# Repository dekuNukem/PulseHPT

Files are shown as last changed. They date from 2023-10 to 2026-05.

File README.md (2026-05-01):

# PulseHPT 3-in-1 Shutter Speed Tester

[Purchase](https://www.tindie.com/products/33002/) | [Discord](https://discord.gg/yyRq8QtX4r) | [Instructions](#user-manual)

---

PulseHPT is a compact shutter speed tester for vintage cameras.

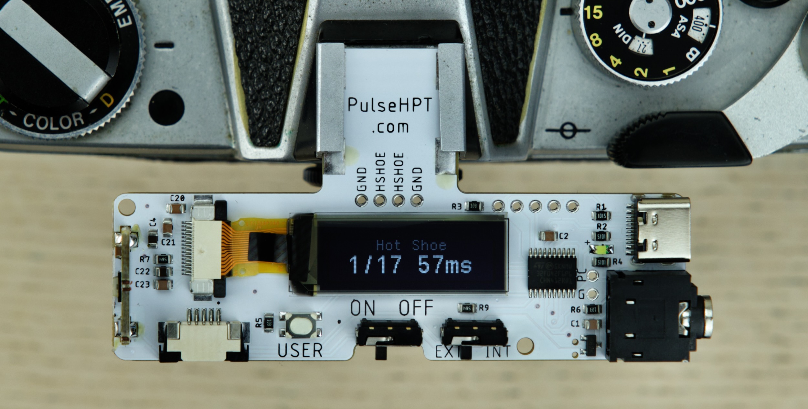
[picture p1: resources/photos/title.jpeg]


Quick and easy measurement from **multiple sources**:

* **Hot Shoe**
* **PC Socket**
* **Light Sensor**
	* Built-in & External
	* Leaf Shutter: All Speeds
	* Focal Plane Shutter: Within Flash Sync

Ideal for **in-the-field testing** of unknown cameras

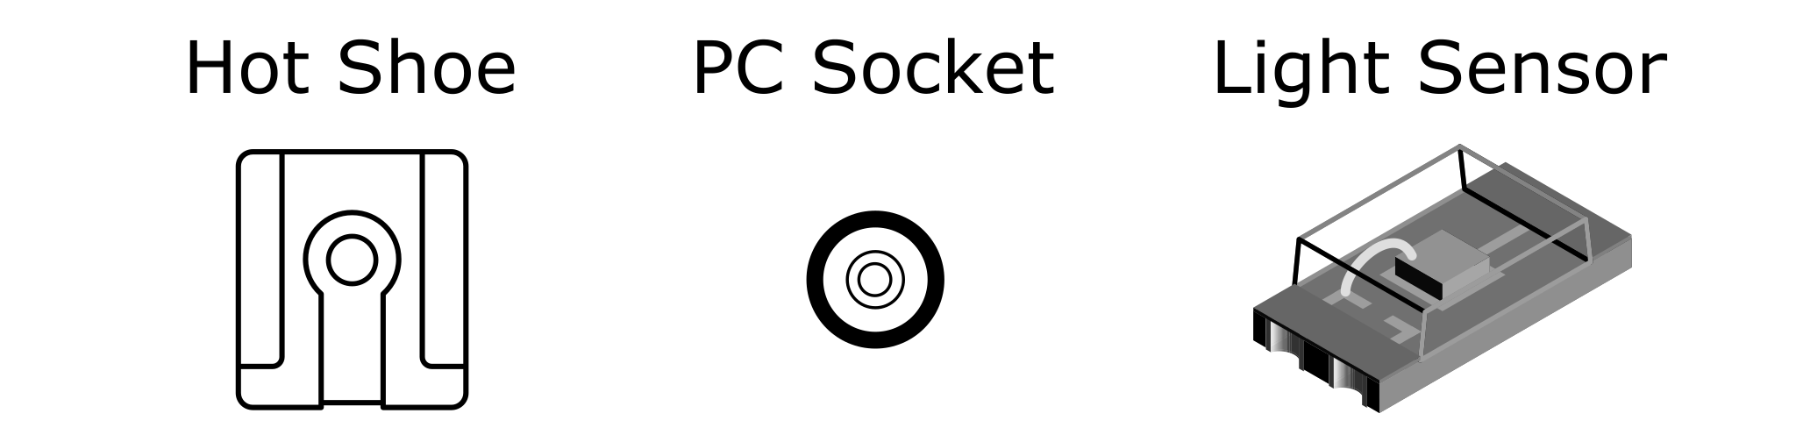
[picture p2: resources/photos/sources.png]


## Highlights

* Compact & Portable

* Multiple Sources

* Microsecond Accuracy

* 20-hour battery / 4000 measurements

## Buy One / Discussions

* United Kingdom: [https://www.ebay.co.uk/itm/365904291256](https://www.ebay.co.uk/itm/365904291256)

* Rest of the world: [https://www.tindie.com/products/33002/](https://www.tindie.com/products/33002/)

[Discord chatroom](https://discord.gg/yyRq8QtX4r) for questions and discussions. Or email `dekuNukem`@`gmail`.`com` .
 
# User Manual

- [Battery](#battery)

- [Hot Shoe](#measurement-hot-shoe)

- [PC Socket](#measurement-pc-socket)

- [Built-in Light Sensor](#measurement-light-sensor)

- [External Light Sensor](#external-light-sensor)

## Battery

* **CR2032**

* Positive (+) side up

* ⚠️ Slide UNDER the catch!

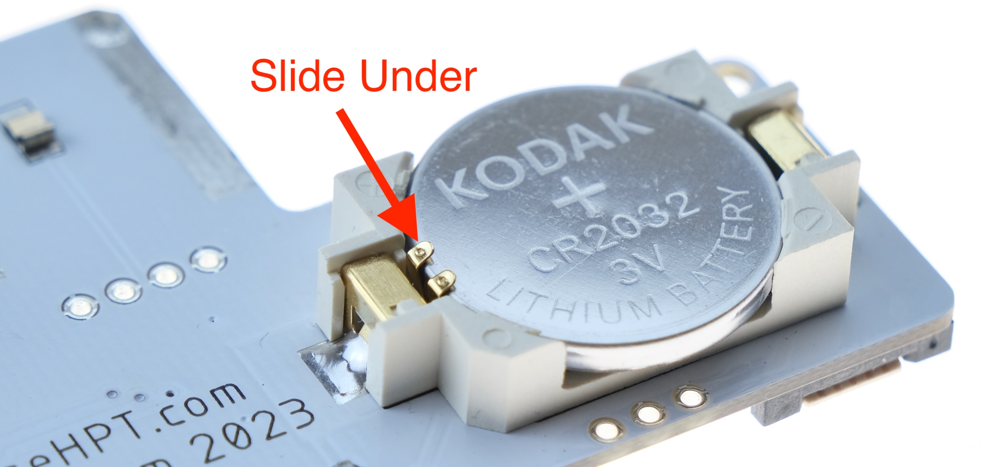
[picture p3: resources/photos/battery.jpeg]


## Measurement: Hot Shoe

* Insert into hot shoe
* Slide switch to ON
* Select a speed
	* Leaf Shutter: All Speeds
	* Focal Plane Shutter: **Within Flash Sync Speed**
* Wind and release the shutter

💭 If nothing happens, press down to ensure good contact.

⚠️ **Beware of caveats!** Read below.



#### How it works

When taking a photo, the flash sync signal activates, and remains active **until shutter is closed**.

Thus the approximate shutter speed can be measured.

#### Caveats

* Flash sync fires **only when shutter is fully open**.

* Thus at higher speeds, the measured speed can be faster than real speed.

* Works best with earlier mostly-mechanical cameras.

* For most accurate result, use the light sensor method.

## Measurement: PC Socket

* Use a common **PC socket to 3.5mm Jack** Cable

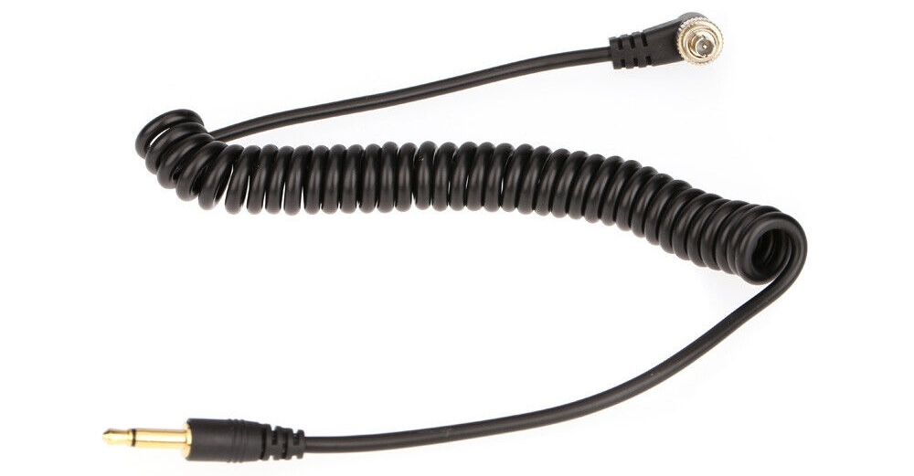
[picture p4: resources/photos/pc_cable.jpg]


* Plug into PC socket, and the other end in the tester.

* ⚠️ ⚠️ Make sure to use `X Sync` socket / option!

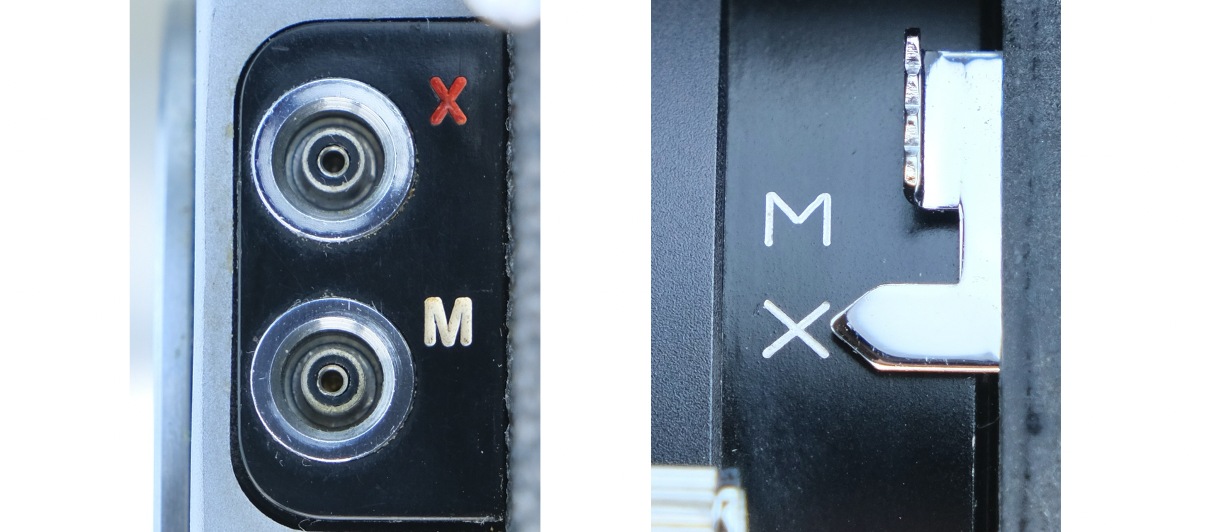
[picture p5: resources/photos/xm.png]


* Slide switch to ON
* Select a speed
	* Leaf Shutter: All Speeds
	* Focal Plane Shutter: **Within Flash Sync Speed**
* Wind and release the shutter

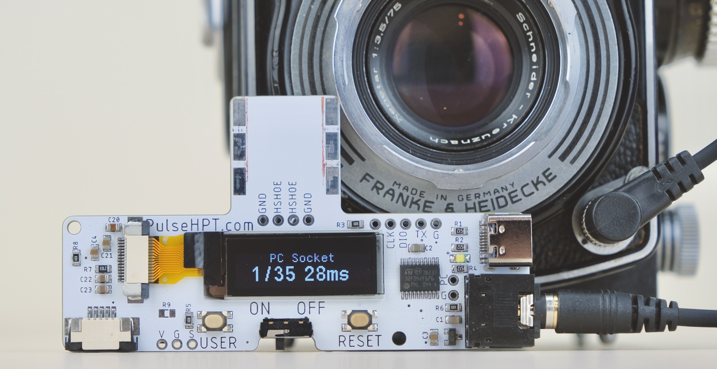
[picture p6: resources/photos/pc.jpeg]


💭 If nothing happens, apply **GENTLE** pressure on the PC socket to ensure good contact.

⚠️ Same caveats as hot shoe!

## Measurement: Light Sensor

* Most accurate
* Two Sources
	* Built-in Sensor: Easiest to Use
	* External Sensor: More Consistent Setup

## Built-in Light Sensor

The built-in sensor sticks out on the left-hand side.

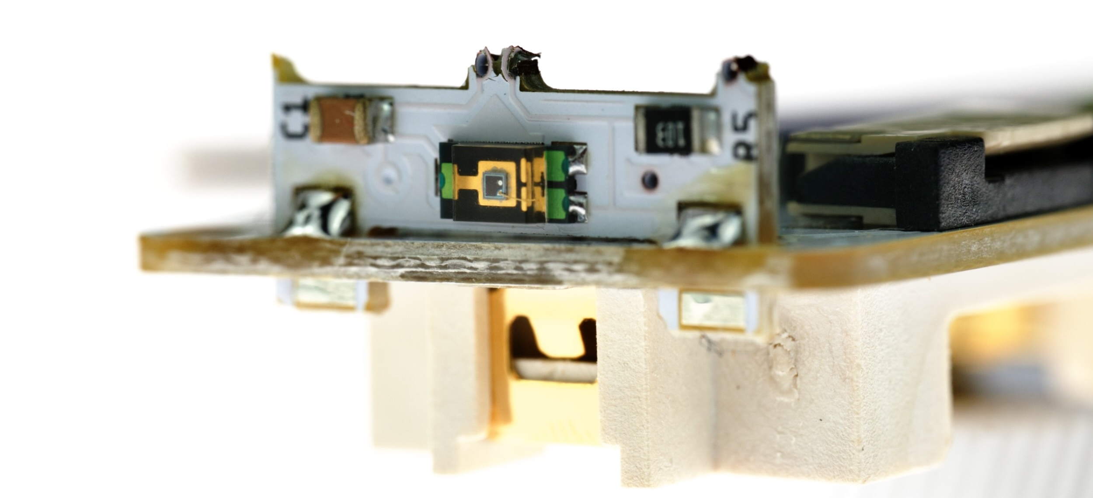
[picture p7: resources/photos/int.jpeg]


Slide the light sensor source switch to `INTERAL` position.

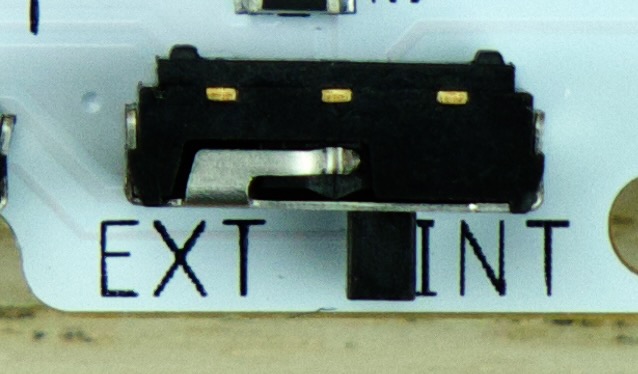
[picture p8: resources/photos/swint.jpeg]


Shine a bright light into the sensor.

It should trigger and give a measurement.

Now you know how bright the light needs to be.

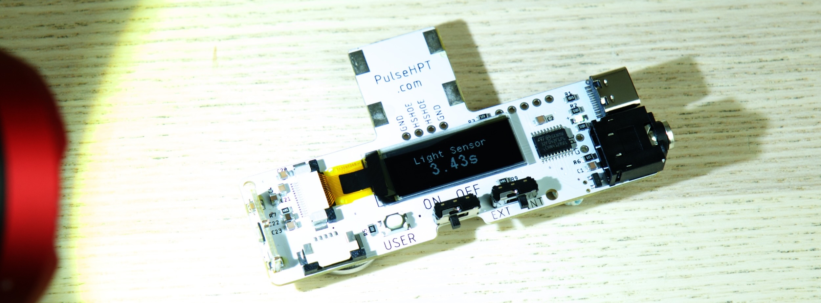
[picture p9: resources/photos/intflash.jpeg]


To test:

* Remove lens if possible
	* Largest aperture otherwise
* Shine light from front
* Place tester **near the center** of film gate
* Fire shutter
	* Leaf Shutter: All Speeds
	* Focal Plane Shutter: **Within Flash Sync Speed**

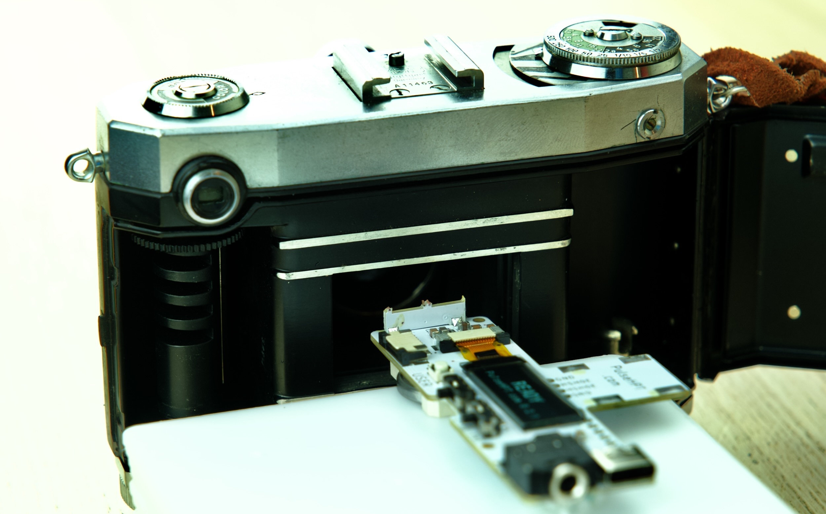
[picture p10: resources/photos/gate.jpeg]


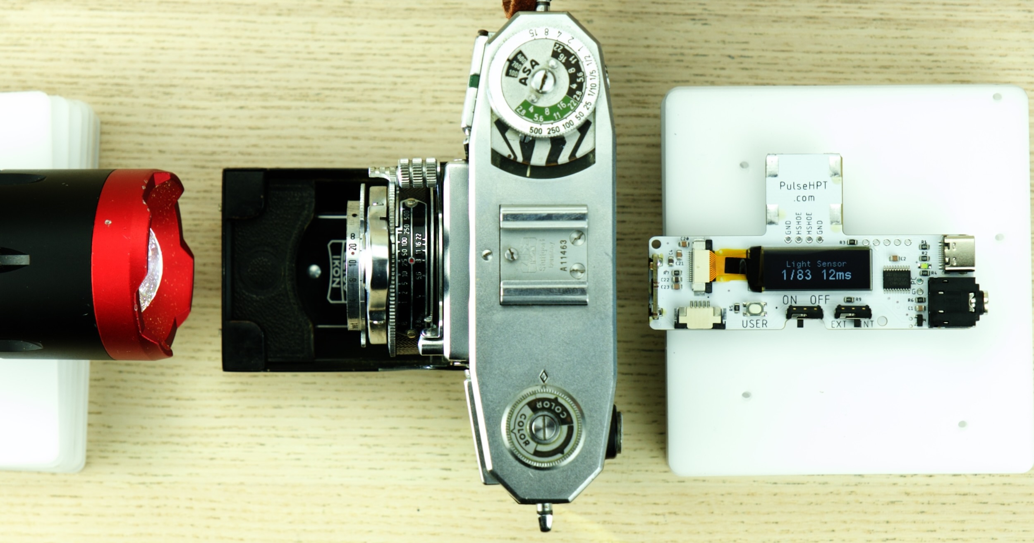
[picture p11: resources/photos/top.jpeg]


## External Light Sensor

Requires more setup, but can be more consistent. Also suitable for hard-to-reach places.

* Locate the connector on **bottom-left corner**.

* **SLOWLY and GENTLY** push the black tab outwards to unlock.

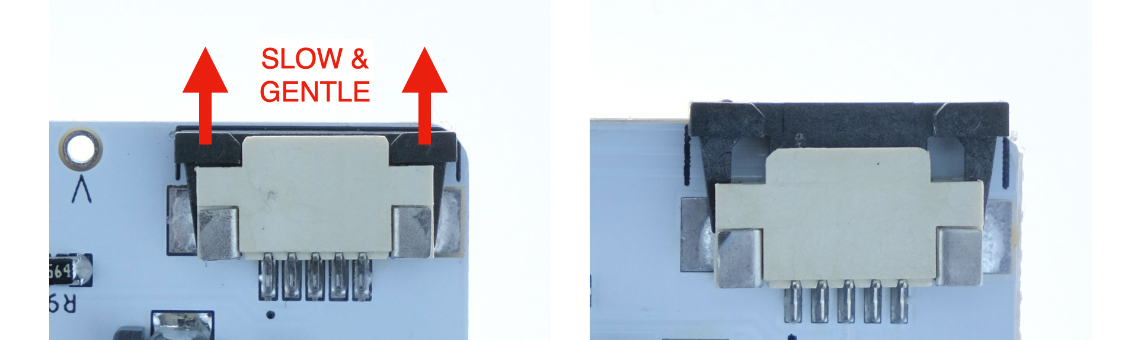
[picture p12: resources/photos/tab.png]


* Insert the ribbon cable **metal contact side up** all the way in

* Push the tab back in to lock

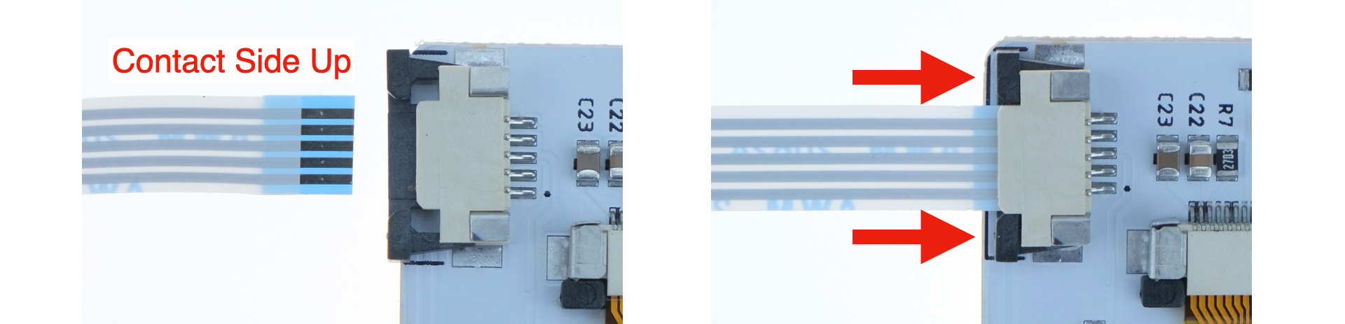
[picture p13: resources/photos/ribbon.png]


* **Do the same** on the sensor side

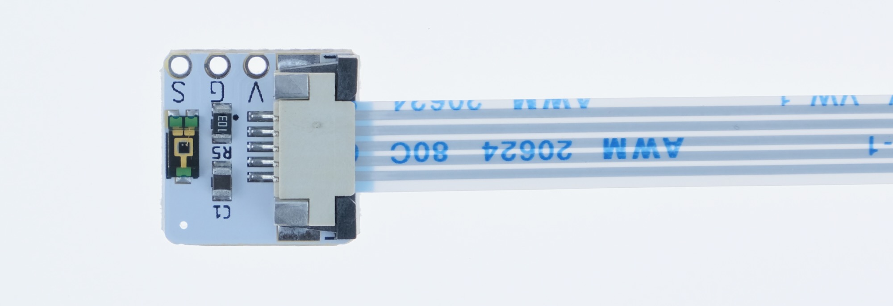
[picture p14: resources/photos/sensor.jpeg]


* Slide Source Switch to `EXTERNAL`

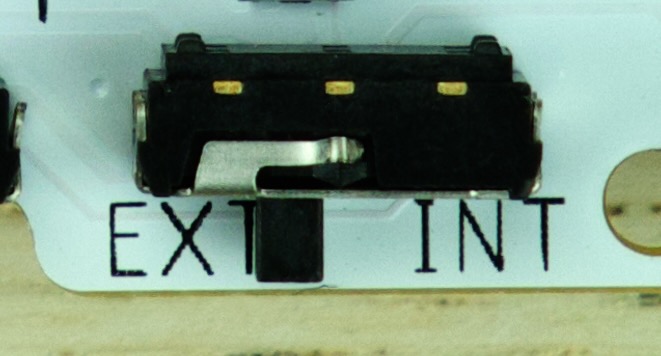
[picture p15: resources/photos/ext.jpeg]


With light sensor connected, let's do a quick test!

* Briefly shine a bright light on the sensor

* Result will be shown

* Now you know how bright the light needs to be

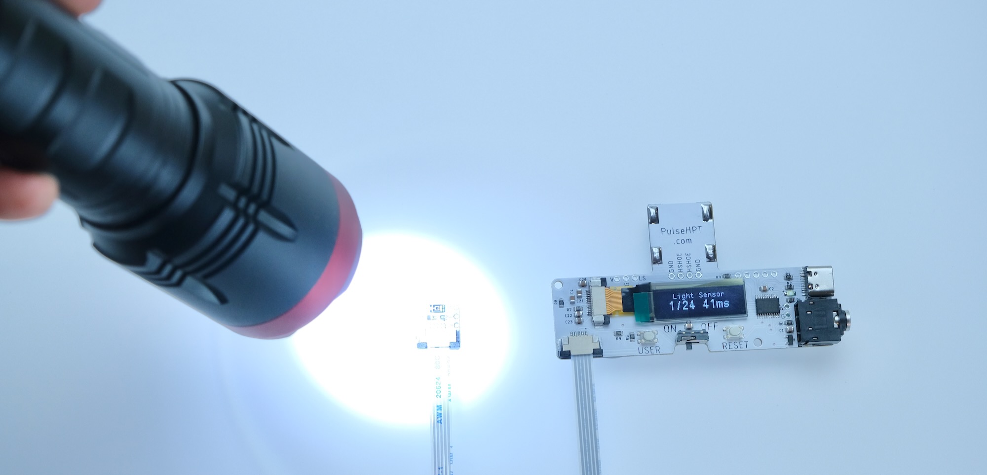
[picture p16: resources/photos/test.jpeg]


Use double side tape, mount the sensor on a vertical surface, e.g. a box.

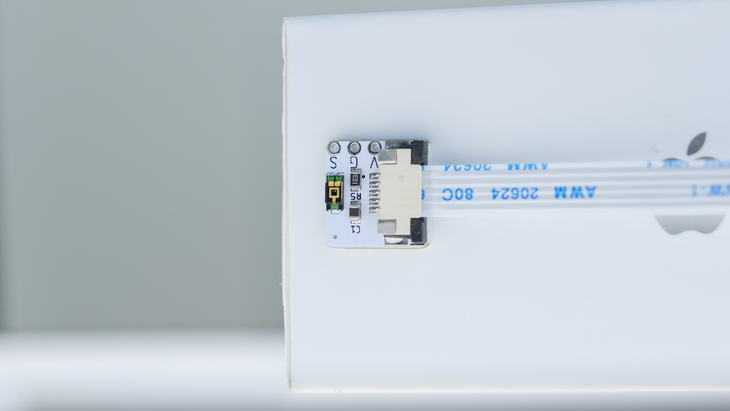
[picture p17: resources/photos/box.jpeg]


* Test **without lens** if possible
	* Largest aperture otherwise
* Sensor behind shutter
* Shine light
* If possible, use Bulb mode to ensure sensor is at the **center of the light circle**.

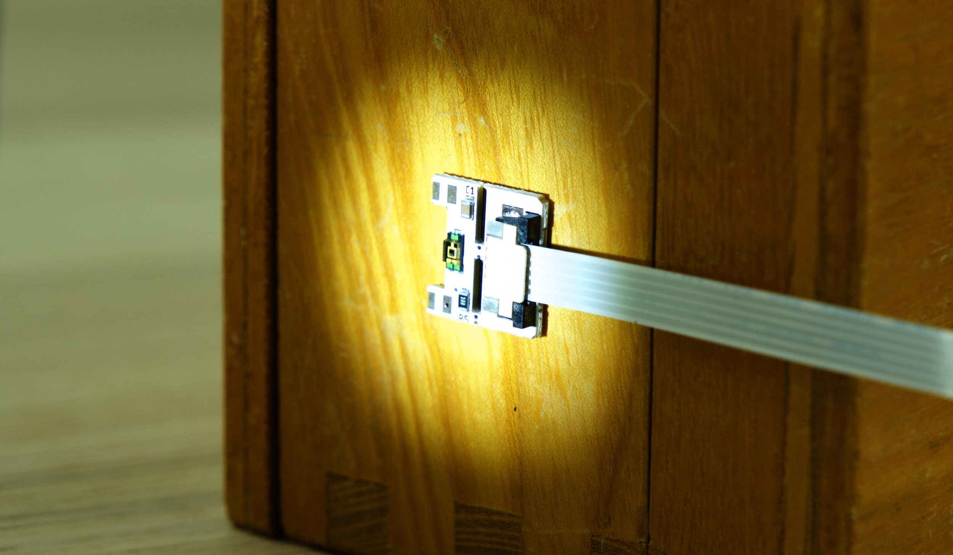
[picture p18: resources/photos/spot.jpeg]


* Fire shutter
	* Leaf Shutter: All Speeds
	* Focal Plane Shutter: **Within Flash Sync Speed**

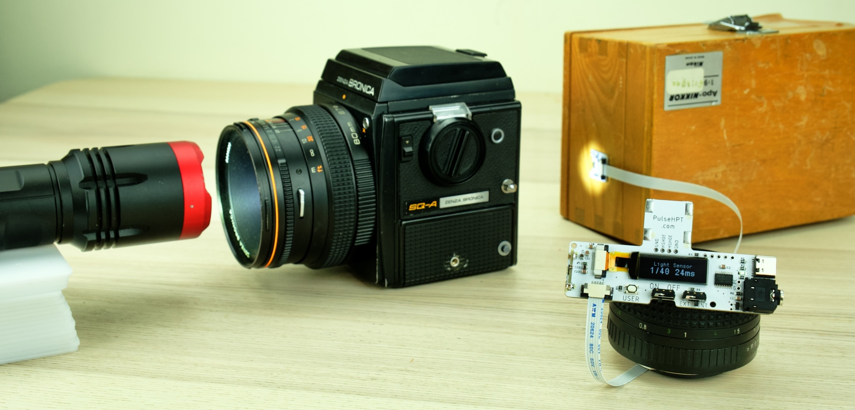
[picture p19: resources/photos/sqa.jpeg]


## Questions or Comments?

[Discord chatroom](https://discord.gg/yyRq8QtX4r) for questions and discussions. Or email `dekuNukem`@`gmail`.`com` .

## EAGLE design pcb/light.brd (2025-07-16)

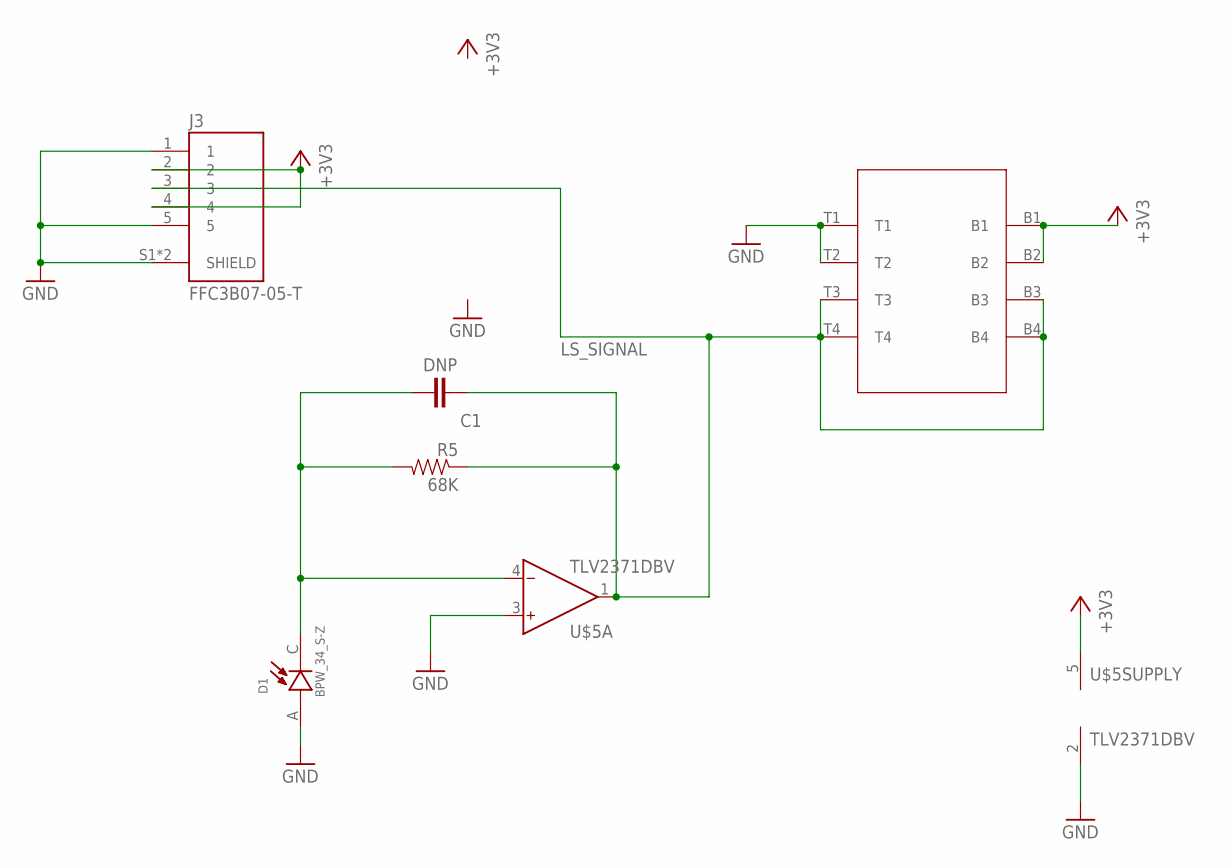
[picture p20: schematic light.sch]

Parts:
C1: DNP; 0805
D1: BPW_34_S-Z; DIO_BPW_34_S-Z
J3: FFC3B07-05-T; GCT_FFC3B07-05-T
R5: 68K; 0805
U$1: LS_VERT
U$5: TLV2371DBV; SOT23-5L

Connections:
+3V3: J3.2, J3.4, U$1.B1, U$1.B2, U$5.5 (V+)
GND: D1.A, J3.1, J3.5, J3.S1 (SHIELD), J3.S2 (SHIELD), U$1.T1, U$1.T2, U$5.2 (V-), U$5.3 (IN+)
LS_SIGNAL: C1.1, J3.3, R5.1, U$1.B3, U$1.B4, U$1.T3, U$1.T4, U$5.1 (OUT)
unnamed: C1.2, D1.C, R5.2, U$5.4 (IN-)

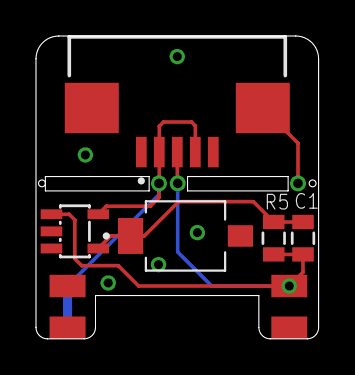
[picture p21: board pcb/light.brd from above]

Board: 2 copper layers, 15.7 x 16.8 mm, 6 parts (0 on the bottom side), 4 nets.

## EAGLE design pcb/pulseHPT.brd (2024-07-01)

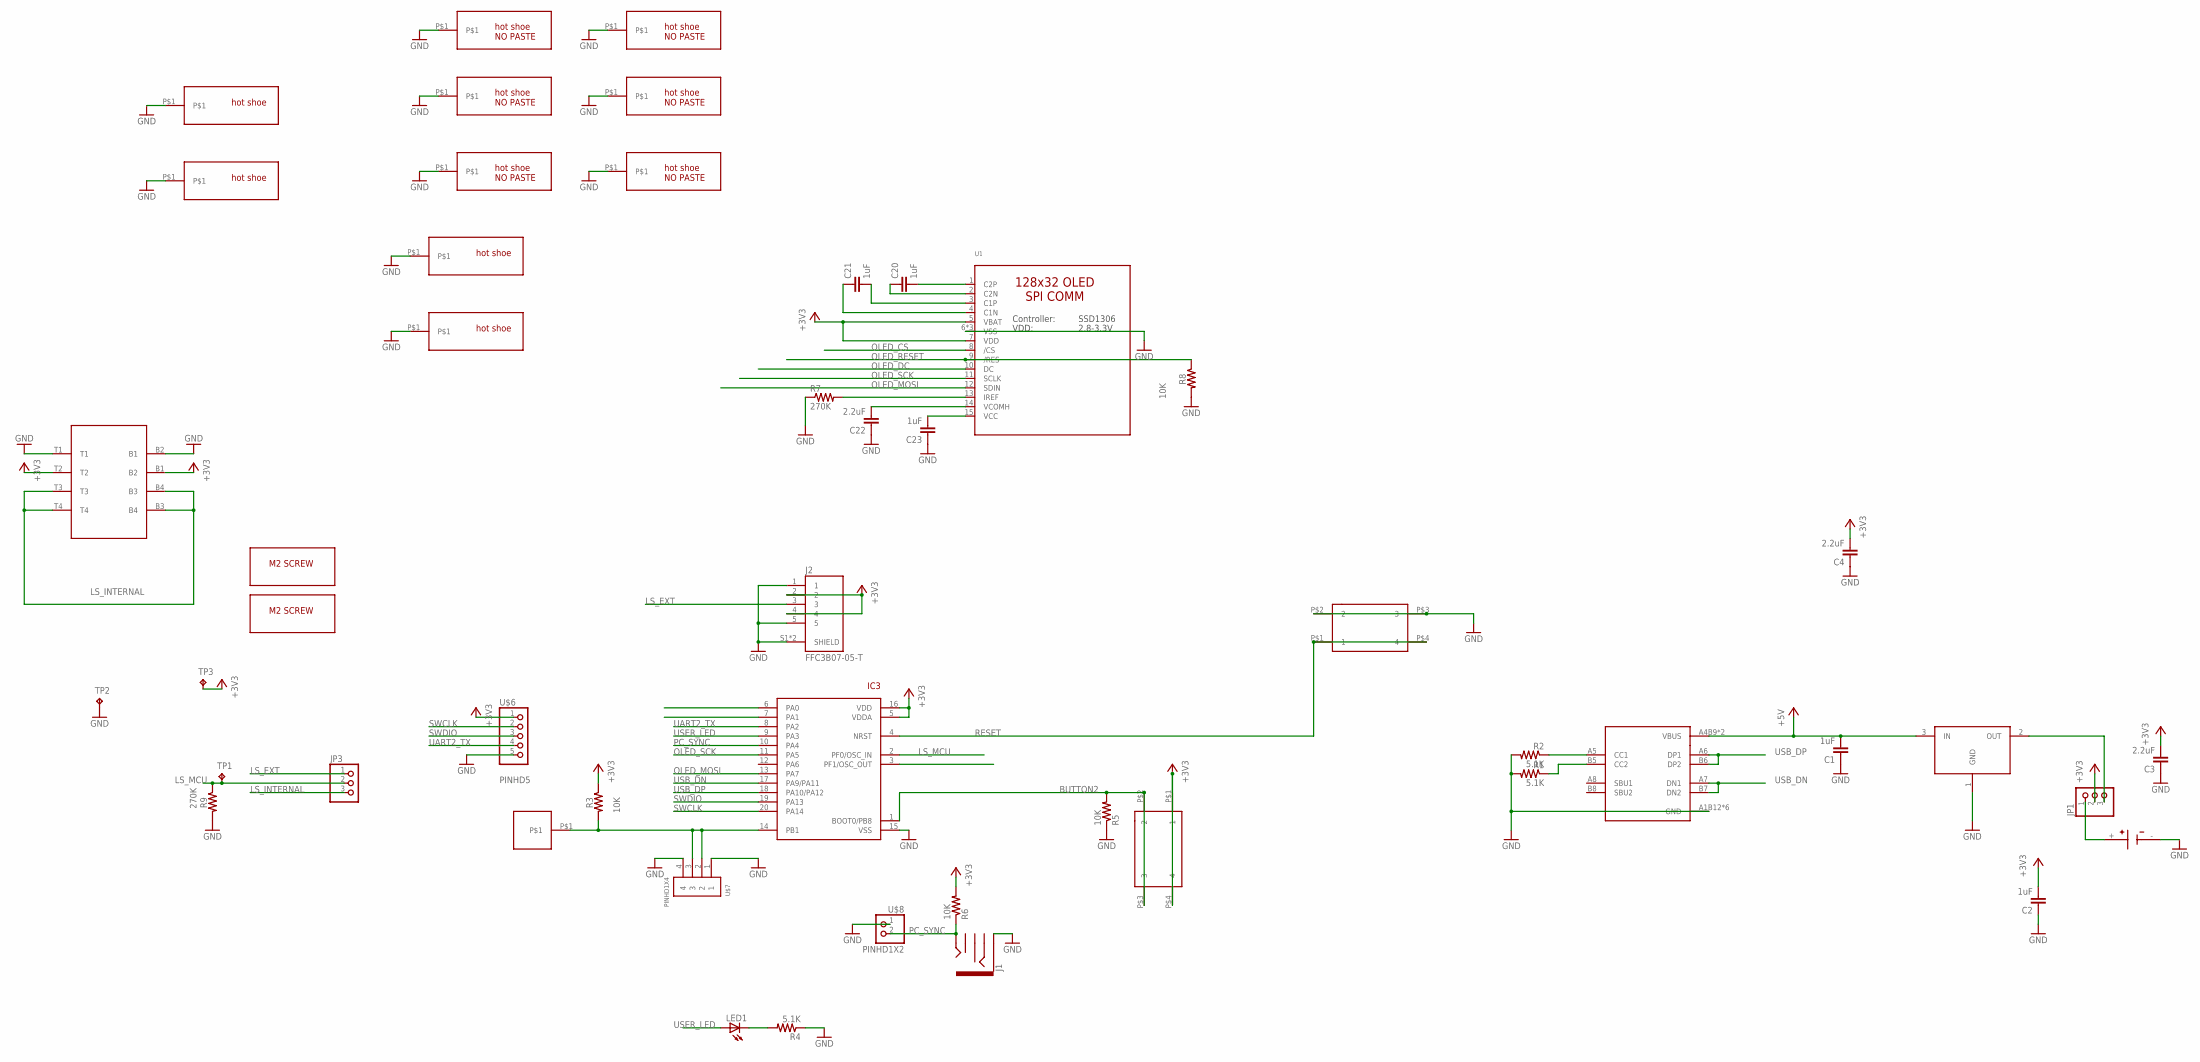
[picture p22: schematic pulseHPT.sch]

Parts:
BT1: BU2032SM-G; BAT_BU2032SM-G
C1, C2, C20, C21, C23: 1uF; 0805
C3, C4, C22: 2.2uF; 0805
IC3: STM32F042F4; TSSOP20
J1: AUDIO_JACK_3.5MM_PTH; AUDIO-JACK
J2: FFC3B07-05-T; GCT_FFC3B07-05-T
JP1, JP3: PINHD-1X3CB; 1X03-CLEANBIG
LED1: LEDCHIP-LED0805; CHIP-LED0805
R1, R2, R4: 5.1K; 0805
R3, R5, R6, R8: 10K; 0805
R7, R9: 270K; 0805
SW3: 324_SW324_SWITCH_FOOT_HOLE; 342_SWICH_FOOT_HOLE
SW4: 324_SW; 342_SWICH_FOOT
TP1, TP2, TP3: TPTP18R; TP18R
U1: LUL_DISP_OLED_UG-2864HSWEG01; LUL_UG-2864HSWEG01_1.3_WRAPAROUND
U2: USBC_16P; USBC_16P_FOOT
U4: XC6206_DEV; SOT23R_INFINEON
U$1, U$12: M2_SCREW_DEV; M2_SCREW_FOOT
U$2: SPRING_CONTACT
U$3, U$4, U$14, U$16: HOTSHOE; HOTSHOE_RAIL
U$5, U$9, U$10, U$11, U$13, U$15: HOTSHOE_NOPASTE; HOTSHOE_RAIL_NOPASTE
U$6: PINHD5; 1X05
U$7: PINHD1X4; 1X04-CLEANBIG
U$8: PINHD1X2; 1X02
U$17: LS_HOLE; LS

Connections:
+3V3: C2.2, C3.2, C4.2, IC3.5 (VDDA), IC3.16 (VDD), J2.2, J2.4, JP1.2, R3.1, R6.2, SW4.P$1 (1), SW4.P$4 (4), TP3.TP, U1.5 (VBAT), U1.7 (VDD), U$6.1, U$17.B1 (B2), U$17.T2
+5V: C1.2, U2.A4B9 (VBUS), U2.B4A9 (VBUS), U4.3 (IN)
BUTTON2: IC3.1 (BOOT0/PB8), R5.2, SW4.P$2 (2), SW4.P$3 (3)
GND: BT1.-, C1.1, C2.1, C3.1, C4.1, C22.1, C23.1, IC3.15 (VSS), J1.SLEEVE, J2.1, J2.5, J2.S1 (SHIELD), J2.S2 (SHIELD), R1.2, R2.2, R4.1, R5.1, R7.1, R8.2, R9.2, SW3.P$2 (2), SW3.P$3 (3), TP2.TP, U1.6 (VSS), U1.16 (VSS), U1.17 (VSS), U2.A1B12 (GND), U2.B11A12 (GND), U2.P$13 (GND), U2.P$14 (GND), U2.P$15 (GND), U2.P$16 (GND), U4.1 (GND), U$3.P$1, U$4.P$1, U$5.P$1, U$6.5, U$7.1, U$7.4, U$8.1, U$9.P$1, U$10.P$1, U$11.P$1, U$13.P$1, U$14.P$1, U$15.P$1, U$16.P$1, U$17.B2 (B1), U$17.T1
LS_EXT: J2.3, JP3.1
LS_INTERNAL: JP3.3, U$17.B3 (B4), U$17.B4 (B3), U$17.T3, U$17.T4
LS_MCU: IC3.2 (PF0/OSC_IN), JP3.2, R9.1, TP1.TP
unnamed: IC3.14 (PB1), R3.2, U$2.P$1, U$7.2, U$7.3
unnamed: JP1.3, U4.2 (OUT)
unnamed: LED1.C, R4.2
unnamed: R1.1, U2.B5 (CC2)
unnamed: R2.1, U2.A5 (CC1)
unnamed: C20.2, U1.1 (C2P)
unnamed: C20.1, U1.2 (C2N)
unnamed: C21.2, U1.3 (C1P)
unnamed: C21.1, U1.4 (C1N)
unnamed: R7.2, U1.13 (IREF)
unnamed: C22.2, U1.14 (VCOMH)
unnamed: C23.2, U1.15 (VCC)
OLED_CS: IC3.3 (PF1/OSC_OUT), U1.8 (/CS)
OLED_DC: IC3.7 (PA1), U1.10 (DC)
OLED_MOSI: IC3.13 (PA7), U1.12 (SDIN)
OLED_RESET: IC3.6 (PA0), R8.1, U1.9 (/RES)
OLED_SCK: IC3.11 (PA5), U1.11 (SCLK)
PC_SYNC: IC3.10 (PA4), J1.TIP, R6.1, U$8.2
RESET: IC3.4 (NRST), SW3.P$1 (1), SW3.P$4 (4)
SWCLK: IC3.20 (PA14), U$6.2
SWDIO: IC3.19 (PA13), U$6.3
UART2_TX: IC3.8 (PA2), U$6.4
USB_DN: IC3.17 (PA9/PA11), U2.A7 (DN1), U2.B7 (DN2)
USB_DP: IC3.18 (PA10/PA12), U2.A6 (DP1), U2.B6 (DP2)
USER_LED: IC3.9 (PA3), LED1.A
VBAT: BT1.+, JP1.1

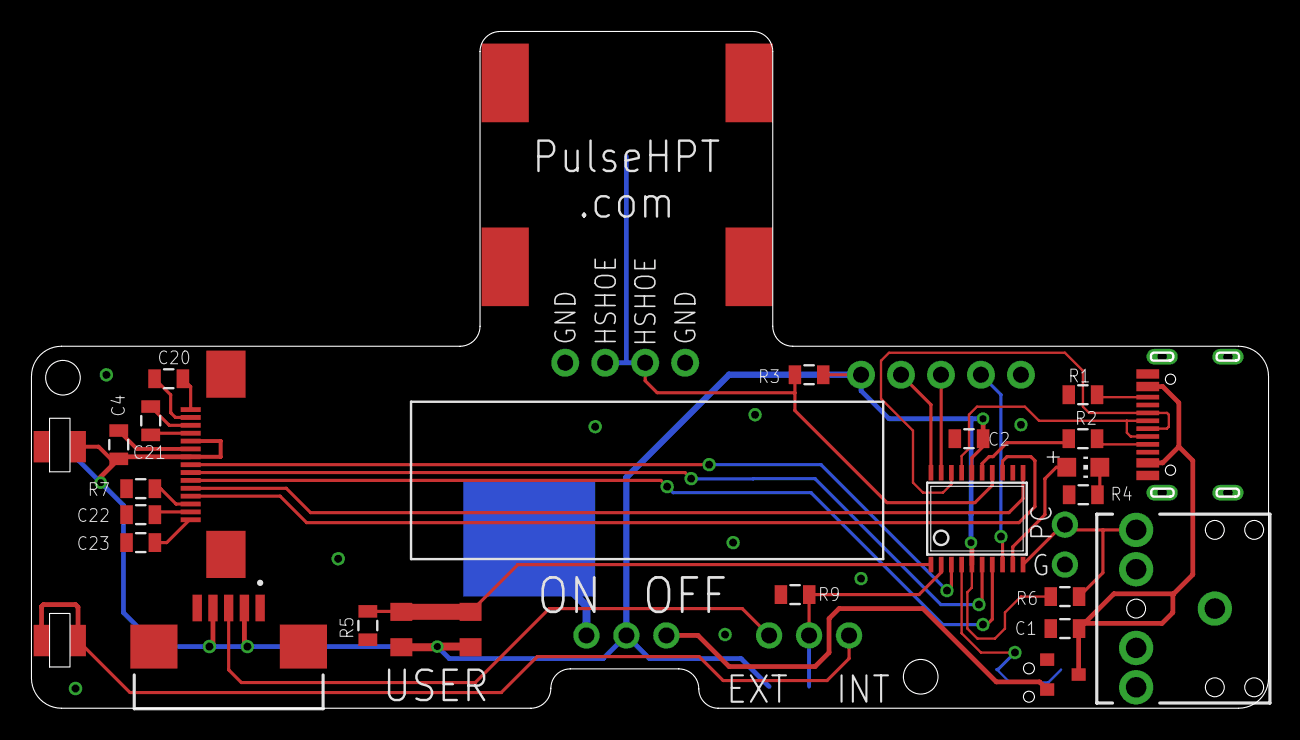
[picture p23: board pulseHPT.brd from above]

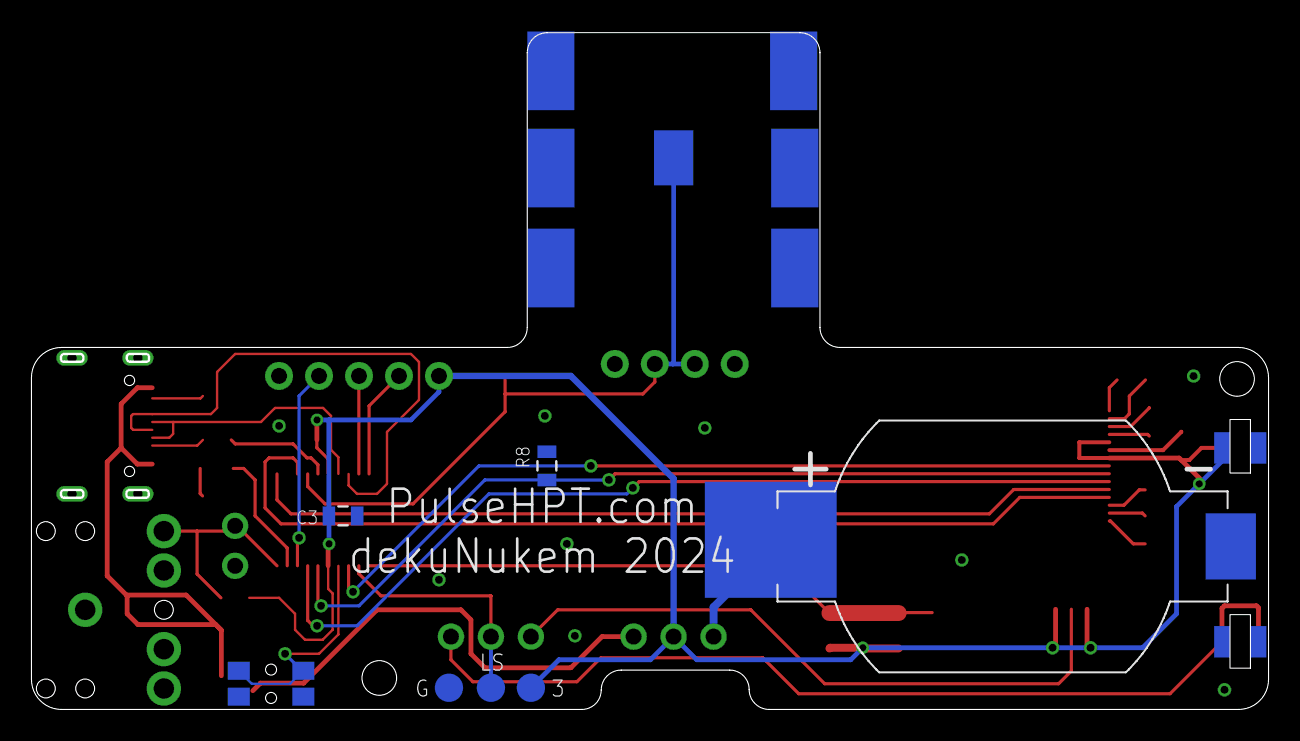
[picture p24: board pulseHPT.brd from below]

Board: 2 copper layers, 78.6 x 43.0 mm, 49 parts (14 on the bottom side), 33 nets.

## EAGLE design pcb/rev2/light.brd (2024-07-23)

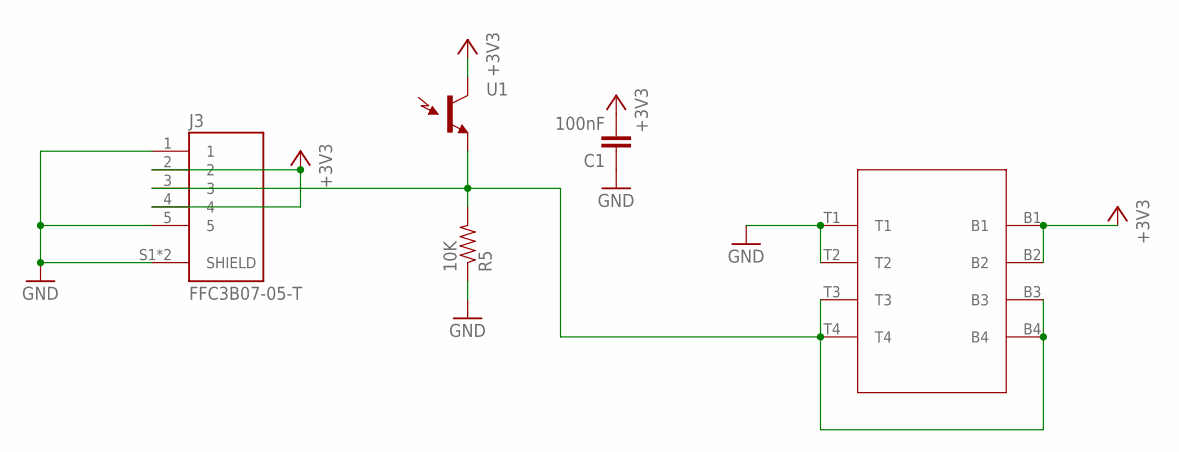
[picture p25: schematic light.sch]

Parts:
C1: 100nF; 0805
J3: FFC3B07-05-T; GCT_FFC3B07-05-T
R5: 10K; 0805
U1: TEMT6000; TEMT6000-SEN
U$1: LS_VERT

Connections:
+3V3: C1.2, J3.2, J3.4, U1.COLLECTOR (C1), U$1.B1, U$1.B2
GND: C1.1, J3.1, J3.5, J3.S1 (SHIELD), J3.S2 (SHIELD), R5.1, U$1.T1, U$1.T2
S: J3.3, R5.2, U1.EMITTER (E1), U$1.B3, U$1.B4, U$1.T3, U$1.T4

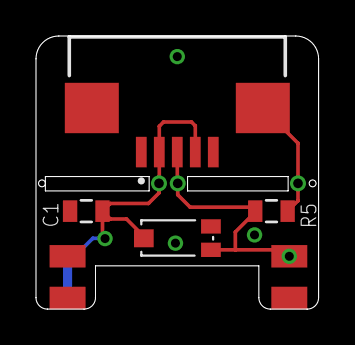
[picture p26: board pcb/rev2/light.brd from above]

Board: 2 copper layers, 15.7 x 15.2 mm, 5 parts (0 on the bottom side), 3 nets.

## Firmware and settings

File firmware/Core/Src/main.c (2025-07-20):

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
/* Includes ------------------------------------------------------------------*/
#include "main.h"

/* USER CODE BEGIN Includes */
#include <stdio.h>
#include "ssd1306.h"
#include <string.h>
/* USER CODE END Includes */

/* USER CODE BEGIN PTD */
int stdin_getchar (void)
{
  return 0;
}

int stdout_putchar (int ch) {
  return 0;
}
void ttywrch (int ch) {
  return;
}
/* USER CODE END PTD */

/* USER CODE BEGIN PD */

/*
2023 11 27 0.2.0
removed OLED dimming
no display fraction when > 600ms when single source
blank out result screen during a new measurement

2023 11 30 0.2.1
skipped blanking out at first measurement

2025 07 20
0.2.2
added 115us of light sensor compensation
*/

uint8_t fw_version_major = 0;
uint8_t fw_version_minor = 2;
uint8_t fw_version_patch = 2;


#define SHUTTER_STATE_IDLE 0
#define SHUTTER_STATE_TRIGGERED 1
#define SHUTTER_STATE_BOUNCE_DETECT 2
#define SHUTTER_STATE_TIMEOUT 3
#define SHUTTER_STATE_RESULT_AVAILABLE 4

#define PIN_STATE_NO_CHANGE 0
#define PIN_STATE_ACTIVATE 1
#define PIN_STATE_RELEASE 2

typedef struct
{
  uint32_t current_state;
  uint32_t trigger_ts;
  uint32_t release_ts;
  uint32_t duration;
  uint32_t bounce_count;
} shutter_state_machine;

void reset_ssm(shutter_state_machine* ssm)
{
  ssm->current_state = SHUTTER_STATE_IDLE;
  ssm->trigger_ts = 0;
  ssm->release_ts = 0;
  ssm->duration = 0;
  ssm->bounce_count = 0;
}

/* USER CODE END PD */

/* USER CODE BEGIN PM */


#define micros() (htim2.Instance->CNT)

/* USER CODE END PM */

SPI_HandleTypeDef hspi1;

TIM_HandleTypeDef htim2;

UART_HandleTypeDef huart2;

/* USER CODE BEGIN PV */

int fputc(int ch, FILE *f)
{
    HAL_UART_Transmit(&huart2, (unsigned char *)&ch, 1, 100);
    return ch;
}

#define SSM_SOURCE_SIZE 3

#define SSM_SOURCE_HOTSHOE 0
#define SSM_SOURCE_PC 1
#define SSM_SOURCE_LIGHT_SENSOR 2

shutter_state_machine all_ssms[SSM_SOURCE_SIZE];

/* USER CODE END PV */

void SystemClock_Config(void);
static void MX_GPIO_Init(void);
static void MX_SPI1_Init(void);
static void MX_USART2_UART_Init(void);
static void MX_TIM2_Init(void);
/* USER CODE BEGIN PFP */

#define SHUTTER_TIMEOUT_SEC 10
#define SHUTTER_BOUNCE_TIMEOUT_MS 250

uint8_t ssm_update(shutter_state_machine* ssm, uint16_t pin_state)
{
  if(ssm->current_state == SHUTTER_STATE_IDLE && pin_state == PIN_STATE_ACTIVATE)
  {
    ssm->current_state = SHUTTER_STATE_TRIGGERED;
    ssm->trigger_ts = micros();
  }
  else if(ssm->current_state == SHUTTER_STATE_TRIGGERED && pin_state == PIN_STATE_RELEASE)
  {
    ssm->current_state = SHUTTER_STATE_BOUNCE_DETECT;
    ssm->release_ts = micros();
  }
  else if(ssm->current_state == SHUTTER_STATE_BOUNCE_DETECT && pin_state == PIN_STATE_ACTIVATE)
  {
    ssm->current_state = SHUTTER_STATE_TRIGGERED;
    ssm->bounce_count++;
  }
  else if(ssm->current_state == SHUTTER_STATE_TRIGGERED && pin_state == PIN_STATE_NO_CHANGE && micros() - ssm->trigger_ts > SHUTTER_TIMEOUT_SEC * 1000 * 1000)
  {
    ssm->current_state = SHUTTER_STATE_TIMEOUT;
  }
  else if(ssm->current_state == SHUTTER_STATE_BOUNCE_DETECT && pin_state == PIN_STATE_NO_CHANGE && micros() - ssm->release_ts > SHUTTER_BOUNCE_TIMEOUT_MS*1000)
  {
    ssm->duration = ssm->release_ts - ssm->trigger_ts;
    ssm->current_state = SHUTTER_STATE_RESULT_AVAILABLE;
  }
  return ssm->current_state;
}

uint8_t pinstate_translate(uint16_t idr_value)
{
  if(idr_value == 0)
  {
    USER_LED_GPIO_Port -> BSRR = USER_LED_Pin;
    return PIN_STATE_ACTIVATE;
  }
  else
  {
    USER_LED_GPIO_Port -> BRR = USER_LED_Pin;
    return PIN_STATE_RELEASE;
  }
}

/* USER CODE END PFP */

/* USER CODE BEGIN 0 */

void HAL_GPIO_EXTI_Callback(uint16_t GPIO_Pin)
{
  if(GPIO_Pin == HOTSHOE_Pin)
    ssm_update(&all_ssms[SSM_SOURCE_HOTSHOE], pinstate_translate(HOTSHOE_GPIO_Port->IDR & HOTSHOE_Pin));
  if(GPIO_Pin == PC_SYNC_Pin)
    ssm_update(&all_ssms[SSM_SOURCE_PC], pinstate_translate(PC_SYNC_GPIO_Port->IDR & PC_SYNC_Pin));
  if(GPIO_Pin == LIGHT_SENSOR_Pin)
    ssm_update(&all_ssms[SSM_SOURCE_LIGHT_SENSOR], pinstate_translate(!(LIGHT_SENSOR_GPIO_Port->IDR & LIGHT_SENSOR_Pin)));
}

#define TEMP_BUF_SIZE 32
char temp_str_buf1[TEMP_BUF_SIZE];
char temp_str_buf2[TEMP_BUF_SIZE];

void format_usec(char* buf, uint32_t time_micros) 
{
  if (time_micros >= 10000000) // More than 10 seconds
    sprintf(buf, "%.1fs", time_micros / 1000000.0);
  else if (time_micros >= 1000000) // More than 1 second
    sprintf(buf, "%.2fs", time_micros / 1000000.0);
  else if (time_micros >= 10000) // More than 10 milliseconds
    sprintf(buf, "%ums", time_micros / 1000);
  else if (time_micros >= 1000) // Between 1 and 10 milliseconds
    sprintf(buf, "%.1fms", time_micros / 1000.0);
  else // Less than 1 millisecond
    sprintf(buf, "%uus", time_micros);
}

float usec_to_fraction(uint32_t usec) 
{
  if(usec == 0)
    return 0;
  return 1000000.0 / usec;
}

void format_fraction(char* buf, uint32_t time_micros) 
{
  float fraction = 0;
  if(time_micros != 0)
    fraction = 1000000.0 / time_micros;

  if(time_micros < 100)
    sprintf(buf, "---");
  else if (fraction >= 10)
    sprintf(buf, "1/%.0f", fraction);
  else
    sprintf(buf, "1/%.1f", fraction);
}

uint8_t center_line(uint8_t line_len, uint8_t char_width_pixels, uint8_t oled_width_pixels)
{
  int16_t start_pixel = (oled_width_pixels - line_len * char_width_pixels) / 2;
  if(start_pixel < 0)
    start_pixel = 0;
  return start_pixel;
}

char* oled_str_hotshoe = "Hot Shoe";
char* oled_str_pc_socket = "PC Socket";
char* oled_str_light_sensor = "Light Sensor";

void print_single_result(char* title, shutter_state_machine* ssm)
{
  if(ssm->duration < 500)
    return;

  ssd1306_Fill(Black);
  ssd1306_SetCursor(center_line(strlen(title), 7, SSD1306_WIDTH), 0);
  ssd1306_WriteString(title, Font_7x10, White);

  format_usec(temp_str_buf1, ssm->duration);
  format_fraction(temp_str_buf2, ssm->duration);

  if(ssm->duration > 600*1000)
    memset(temp_str_buf2, 0, TEMP_BUF_SIZE);
  else
    strcat(temp_str_buf2, " ");

  uint8_t line_start = center_line(strlen(temp_str_buf1)+strlen(temp_str_buf2), 11, SSD1306_WIDTH);
  ssd1306_SetCursor(line_start, 11);

  ssd1306_WriteString(temp_str_buf2, Font_11x18, White);
  ssd1306_WriteString(temp_str_buf1, Font_11x18, White);

  ssd1306_UpdateScreen();
}

void print_double_result(char* title1, shutter_state_machine* ssm1, char* title2, shutter_state_machine* ssm2)
{
  ssd1306_Fill(Black);

  ssd1306_Line(63,0,63,32,White);

  ssd1306_SetCursor(center_line(strlen(title1), 7, SSD1306_WIDTH/2), 0);
  ssd1306_WriteString(title1, Font_7x10, White);

  ssd1306_SetCursor(center_line(strlen(title2), 7, SSD1306_WIDTH/2) + 64, 0);
  ssd1306_WriteString(title2, Font_7x10, White);

  format_usec(temp_str_buf1, ssm1->duration);
  format_fraction(temp_str_buf2, ssm1->duration);

  ssd1306_SetCursor(center_line(strlen(temp_str_buf1), 7, SSD1306_WIDTH/2), 11);
  ssd1306_WriteString(temp_str_buf1, Font_7x10, White);

  ssd1306_SetCursor(center_line(strlen(temp_str_buf2), 7, SSD1306_WIDTH/2), 22);
  ssd1306_WriteString(temp_str_buf2, Font_7x10, White);

  format_usec(temp_str_buf1, ssm2->duration);
  format_fraction(temp_str_buf2, ssm2->duration);

  ssd1306_SetCursor(center_line(strlen(temp_str_buf1), 7, SSD1306_WIDTH/2) + 64, 11);
  ssd1306_WriteString(temp_str_buf1, Font_7x10, White);

  ssd1306_SetCursor(center_line(strlen(temp_str_buf2), 7, SSD1306_WIDTH/2) + 64, 22);
  ssd1306_WriteString(temp_str_buf2, Font_7x10, White);

  ssd1306_UpdateScreen();
}

void print_triple_result(void)
{
  ssd1306_Fill(Black);

  ssd1306_SetCursor(center_line(strlen("HS"), 7, SSD1306_WIDTH/3), 0);
  ssd1306_WriteString("HS", Font_7x10, White);

  ssd1306_SetCursor(center_line(strlen("PC"), 7, SSD1306_WIDTH/3) + 42, 0);
  ssd1306_WriteString("PC", Font_7x10, White);

  ssd1306_SetCursor(center_line(strlen("LS"), 7, SSD1306_WIDTH/3) + 84, 0);
  ssd1306_WriteString("LS", Font_7x10, White);

  //-------------HOT SHOE-----------------
  format_usec(temp_str_buf1, all_ssms[SSM_SOURCE_HOTSHOE].duration);
  format_fraction(temp_str_buf2, all_ssms[SSM_SOURCE_HOTSHOE].duration);

  ssd1306_SetCursor(center_line(strlen(temp_str_buf1), 7, SSD1306_WIDTH/3), 11);
  ssd1306_WriteString(temp_str_buf1, Font_7x10, White);

  ssd1306_SetCursor(center_line(strlen(temp_str_buf2), 7, SSD1306_WIDTH/3), 22);
  ssd1306_WriteString(temp_str_buf2, Font_7x10, White);

  //-------------PC SOCKET-----------------
  format_usec(temp_str_buf1, all_ssms[SSM_SOURCE_PC].duration);
  format_fraction(temp_str_buf2, all_ssms[SSM_SOURCE_PC].duration);

  ssd1306_SetCursor(center_line(strlen(temp_str_buf1), 7, SSD1306_WIDTH/3) + 42, 11);
  ssd1306_WriteString(temp_str_buf1, Font_7x10, White);

  ssd1306_SetCursor(center_line(strlen(temp_str_buf2), 7, SSD1306_WIDTH/3) + 42 , 22);
  ssd1306_WriteString(temp_str_buf2, Font_7x10, White);

  //-------------LIGHT SENSOR-----------------
  format_usec(temp_str_buf1, all_ssms[SSM_SOURCE_LIGHT_SENSOR].duration);
  format_fraction(temp_str_buf2, all_ssms[SSM_SOURCE_LIGHT_SENSOR].duration);

  ssd1306_SetCursor(center_line(strlen(temp_str_buf1), 7, SSD1306_WIDTH/3) + 84, 11);
  ssd1306_WriteString(temp_str_buf1, Font_7x10, White);

  ssd1306_SetCursor(center_line(strlen(temp_str_buf2), 7, SSD1306_WIDTH/3) + 84 , 22);
  ssd1306_WriteString(temp_str_buf2, Font_7x10, White);

  ssd1306_Line(42,0,42,32,White);
  ssd1306_Line(85,0,85,32,White);

  ssd1306_UpdateScreen();
}

char* oled_str_ready = "READY";

void print_ready(void)
{
  ssd1306_Fill(Black);
  ssd1306_SetCursor(center_line(strlen(oled_str_ready), 11, SSD1306_WIDTH), 0);
  ssd1306_WriteString(oled_str_ready, Font_11x18, White);

  memset(temp_str_buf1, 0, TEMP_BUF_SIZE);
  sprintf(temp_str_buf1, "PulseHPT.com %d.%d.%d", fw_version_major, fw_version_minor, fw_version_patch);
  ssd1306_SetCursor(0, 20);
  ssd1306_WriteString(temp_str_buf1, Font_7x10, White);
  ssd1306_UpdateScreen();
}

void delay_us(uint32_t delay)
{
  uint32_t end_time = micros() + delay;
  while(micros() < end_time);
}

uint8_t count_state(uint8_t state)
{
  uint8_t bitfield = 0;
  for (uint8_t i = 0; i < SSM_SOURCE_SIZE; i++)
    if(all_ssms[i].current_state == state)
      bitfield |= 1 << i;
  return bitfield;
}

void ssm_reset_all(void)
{
  reset_ssm(&all_ssms[SSM_SOURCE_HOTSHOE]);
  reset_ssm(&all_ssms[SSM_SOURCE_PC]);
  reset_ssm(&all_ssms[SSM_SOURCE_LIGHT_SENSOR]);
}

void ssm_update_all(void)
{
  ssm_update(&all_ssms[SSM_SOURCE_HOTSHOE], PIN_STATE_NO_CHANGE);
  ssm_update(&all_ssms[SSM_SOURCE_PC], PIN_STATE_NO_CHANGE);
  ssm_update(&all_ssms[SSM_SOURCE_LIGHT_SENSOR], PIN_STATE_NO_CHANGE);
}

#define LIGHT_SENSOR_COMPENSATION_US 115

void print_results_all_sources(void)
{
  uint8_t active_sources = count_state(SHUTTER_STATE_RESULT_AVAILABLE);
  /*
  4  3  2  1
  X  LS PC HS
  */

  all_ssms[SSM_SOURCE_LIGHT_SENSOR].duration -= LIGHT_SENSOR_COMPENSATION_US;

  if(active_sources == 1) // 0001 hot shoe only
    print_single_result(oled_str_hotshoe, &all_ssms[SSM_SOURCE_HOTSHOE]);

  else if(active_sources == 2) // 0010 pc only
    print_single_result(oled_str_pc_socket, &all_ssms[SSM_SOURCE_PC]);

  else if(active_sources == 4) // 0100 light sensor only
    print_single_result(oled_str_light_sensor, &all_ssms[SSM_SOURCE_LIGHT_SENSOR]);

  else if(active_sources == 3) // 0011 hot shoe AND pc
    print_double_result("HotShoe", &all_ssms[SSM_SOURCE_HOTSHOE], "PC", &all_ssms[SSM_SOURCE_PC]);

  else if(active_sources == 5) // 0101 hot shoe AND light sensor
    print_double_result("HotShoe", &all_ssms[SSM_SOURCE_HOTSHOE], "L Sensor", &all_ssms[SSM_SOURCE_LIGHT_SENSOR]);

  else if(active_sources == 6) // 0110 pc AND light sensor
    print_double_result("PC", &all_ssms[SSM_SOURCE_PC], "L Sensor", &all_ssms[SSM_SOURCE_LIGHT_SENSOR]);

  else if(active_sources == 7) // 0111 all of them
    print_triple_result();
}

void print_timeout(void)
{
  ssd1306_Fill(Black);
  memset(temp_str_buf1, 0, TEMP_BUF_SIZE);
  sprintf(temp_str_buf1, " >%ds", SHUTTER_TIMEOUT_SEC);
  ssd1306_SetCursor(0, 7);
  ssd1306_WriteString("TIMEOUT", Font_11x18, White);
  ssd1306_SetCursor(80, 11);
  ssd1306_WriteString(temp_str_buf1, Font_7x10, White);
  ssd1306_UpdateScreen();
}

/* USER CODE END 0 */

/**
  * @brief  The application entry point.
  * @retval int
  */
int main(void)
{
  /* MCU Configuration--------------------------------------------------------*/

  /* Reset of all peripherals, Initializes the Flash interface and the Systick. */
  HAL_Init();

  /* Configure the system clock */
  SystemClock_Config();

  /* Initialize all configured peripherals */
  MX_GPIO_Init();
  MX_SPI1_Init();
  MX_USART2_UART_Init();
  MX_TIM2_Init();
  /* USER CODE BEGIN 2 */
  ssd1306_Init();
  HAL_TIM_Base_Start(&htim2);
  ssm_reset_all();
  ssd1306_SetContrast(128); // 0 least bright, 255 full brightness

  /* USER CODE END 2 */

  /* Infinite loop */
  /* USER CODE BEGIN WHILE */
  printf("PulseHPT dekuNukem 2023 %d.%d.%d\n", fw_version_major, fw_version_minor, fw_version_patch);
  print_ready();
  uint8_t is_first_measurement = 1;
  while (1)
  {
    /* USER CODE END WHILE */

    /* USER CODE BEGIN 3 */
    HAL_Delay(10);
    ssm_update_all();

    if(count_state(SHUTTER_STATE_TIMEOUT))
    {
      __disable_irq();
      print_timeout();
      delay_us(250*1000);
      ssm_reset_all();
      __enable_irq();
      continue;
    }

    if(count_state(SHUTTER_STATE_RESULT_AVAILABLE) == 0)
      continue;

    if(!is_first_measurement)
    {
      ssd1306_FillRectangle(0,11,127,31,Black);
      ssd1306_UpdateScreen();
    }
    
    // at least one source has result 
    // wait a bit more and see if other sources has results too
    uint32_t entry_time = micros();
    while(micros() - entry_time < 250*1000)
    {
      HAL_Delay(10);
      ssm_update_all();
    }

    __disable_irq();
    print_results_all_sources();
    delay_us(100*1000);
    ssm_reset_all();
    __enable_irq();
    is_first_measurement = 0;
  }
  /* USER CODE END 3 */
}

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


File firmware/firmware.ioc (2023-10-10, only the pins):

Mcu.UserName=STM32F042F6Px
PA0.GPIO_Label=OLED_RESET
PA0.Signal=GPIO_Output
PA1.GPIO_Label=OLED_DC
PA1.Signal=GPIO_Output
PA13.Signal=SYS_SWDIO
PA14.Signal=SYS_SWCLK
PA2.Signal=USART2_TX
PA3.GPIO_Label=USER_LED
PA3.Signal=GPIO_Output
PA4.GPIO_Label=PC_SYNC
PA4.Signal=GPXTI4
PA5.Signal=SPI1_SCK
PA6.Signal=SPI1_MISO
PA7.Signal=SPI1_MOSI
PB1.GPIO_Label=HOTSHOE
PB1.Signal=GPXTI1
PB8.GPIO_Label=USER_BUTTON
PB8.Signal=GPIO_Input
PF0-OSC_IN.GPIO_Label=LIGHT_SENSOR
PF0-OSC_IN.Signal=GPXTI0
PF1-OSC_OUT.GPIO_Label=OLED_CS
PF1-OSC_OUT.Signal=GPIO_Output

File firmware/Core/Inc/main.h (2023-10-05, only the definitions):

#define USER_BUTTON_Pin GPIO_PIN_8
#define USER_BUTTON_GPIO_Port GPIOB
#define LIGHT_SENSOR_Pin GPIO_PIN_0
#define LIGHT_SENSOR_GPIO_Port GPIOF
#define LIGHT_SENSOR_EXTI_IRQn EXTI0_1_IRQn
#define OLED_CS_Pin GPIO_PIN_1
#define OLED_CS_GPIO_Port GPIOF
#define OLED_RESET_Pin GPIO_PIN_0
#define OLED_RESET_GPIO_Port GPIOA
#define OLED_DC_Pin GPIO_PIN_1
#define OLED_DC_GPIO_Port GPIOA
#define USER_LED_Pin GPIO_PIN_3
#define USER_LED_GPIO_Port GPIOA
#define PC_SYNC_Pin GPIO_PIN_4
#define PC_SYNC_GPIO_Port GPIOA
#define PC_SYNC_EXTI_IRQn EXTI4_15_IRQn
#define HOTSHOE_Pin GPIO_PIN_1
#define HOTSHOE_GPIO_Port GPIOB
#define HOTSHOE_EXTI_IRQn EXTI0_1_IRQn

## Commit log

2023-09-23 working on pcb
    [pmm.brd, pmm.sch]
2023-09-23 hotshoe done
    [pmm.brd, pmm.sch]
2023-09-24 light sensor PCB
    [light.brd, light.sch, pmm.brd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]
2023-09-24 shortened left side
    [pmm.brd, pmm.sch]
2023-09-24 added website
    [light.brd, light.sch, pmm.brd]
2023-09-24 finishing touches
    [pmm.brd, pmm.sch]
2023-10-06 microsecond timer and exti both edge working
2023-10-06 interrupt source working
2023-10-06 reading pin state
2023-10-07 fast LED toggle
2023-10-07 centered print, result horizotal
2023-10-08 PC socket result print
2023-10-08 before switching to sss array
2023-10-09 double triple print working
2023-10-09 added gnd via on light sensor board, fixed silkscreen
    [light.brd]
2023-10-09 fixed light sensor polarity
    [pmm.brd]
2023-10-09 added pulldown on light sensor pin, pcb cleanup
    [pmm.brd, pmm.sch]
2023-10-09 added spring contacts
    [pmm.brd, pmm.sch]
2023-10-09 pcb cleanup
    [pmm.brd]
2023-10-10 added version number display, fixed bugs
    [main.c, scraps.c]
2023-10-13 adjusted resistor values
    [pmm.brd, pmm.sch]
2023-10-16 updated PCB
    [pmm.brd, pmm.sch]
2023-10-20 adjusted PCB
    [pmm.brd, pmm.sch]
2023-10-24 cleaning up pcb
    [pmm.brd, pmm.sch]
2023-11-12 switched the result display around
2023-11-30 skipped blanking out for first measurement
    [main.c]
2023-12-01 added light sensor instruction
2024-02-02 working on improvments
    [light.brd, light.sch, pmm.brd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]
2024-02-27 adjusted for pcb thickness
    [light.brd, light.sch, pmm.brd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]
2024-07-01 reset button
    [pmm.brd, pmm.sch]
2024-07-23 adjusted traces
    [light.brd]
2024-10-20 updated instructions for new revision with built-in sensor
2025-07-04 cleanup PCB files
    [light.brd, light.sch, pmm.brd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]
2025-07-07 adjusted resistor
    [light.brd]
2025-07-16 adjusted gain resistor values, added more captures
    [light.brd, light.sch]
2025-07-16 added notes
    [light.brd]
2025-07-20 adjusted light sensor compensation

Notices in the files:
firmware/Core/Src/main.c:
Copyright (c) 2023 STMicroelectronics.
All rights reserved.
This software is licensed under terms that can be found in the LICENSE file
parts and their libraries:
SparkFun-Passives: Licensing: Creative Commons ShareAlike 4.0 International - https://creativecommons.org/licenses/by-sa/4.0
